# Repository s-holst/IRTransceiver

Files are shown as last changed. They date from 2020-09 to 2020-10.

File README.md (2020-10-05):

# IRTransceiver

A [Pmod](https://reference.digilentinc.com/reference/pmod/start) for emitting and receiving baseband IR signals.
It can be used to decode and emulate IR remote controls, IR communication or other IR-based sensors.

<p align="center">
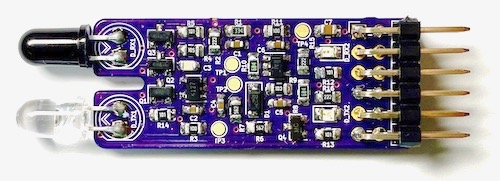
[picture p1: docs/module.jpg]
IR Transceiver Pmod Image
  
</p>

This module contains simple analog signal conditioning circuitry to connect a LED and a photodiode to FPGAs or microcontrollers.
The interface is a 12-pin Pmod (Spec B) with the following pinout:
* P1: TX, input, active high, controls the IR LED via a simple MOSFET.
* P2: GND
* P3: RX, output, is pulled high if the photodiode receives a stronger-than-average IR light.
* P4: GND
* P5, P11: GND (Pmod power supply pins)
* P6, P12: 3.3V (Pmod power supply pins)
* P7-P10: Not connected

The receiver contains a transimpedance amplifier, a high-pass filter and comparator to produce a clean digital signal.
The high-pass rejects ambient light along with signals slower than about 10 kHz, the usable bandwidth is about 100 kHz.
The receiver circuit was inspired by [IRis](https://github.com/devttys0/IRis).

## PYNQ Example Notebook

If you have a PYNQ-enabled FPGA-board, load [PYNQ_IR_Communication.ipynb](PYNQ_IR_Communication.ipynb) onto it to explore an example of sending and receiving IR signals.
This notebook works with the BaseOverlay and is completely self-contained not needing any additional drivers.
It expects an IRTransceiver connected to PMODA.

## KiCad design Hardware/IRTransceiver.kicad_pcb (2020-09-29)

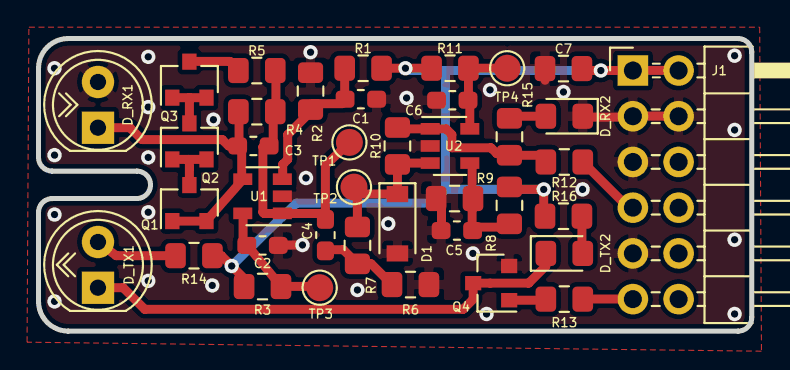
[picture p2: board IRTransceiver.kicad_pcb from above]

Board: 2 copper layers, 39.6 x 16.3 mm, 40 parts (1 on the bottom side), 21 nets.

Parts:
C1, C2, C4, C5, C6: 100n; C_0603_1608Metric_Pad1.05x0.95mm_HandSolder
C3: 2p2; C_0603_1608Metric_Pad1.05x0.95mm_HandSolder
C7: 10u; C_0805_2012Metric_Pad1.15x1.40mm_HandSolder
D1: MBR0520; D_SOD-123
D_RX1: SFH213FA; LED_D5.0mm_IRBlack
D_RX2: LED YELLOW; LED_0805_2012Metric_Pad1.15x1.40mm_HandSolder
D_TX1: SFH4550; LED_D5.0mm_IRGrey
D_TX2: LED BL; LED_0805_2012Metric_Pad1.15x1.40mm_HandSolder
J1: Conn_02x06_Top_Bottom; PinHeader_2x06_P2.54mm_Horizontal
LOGO1: Logo_Open_Hardware_Small; OSHW-Logo_7.5x8mm_SilkScreen
Q1, Q2, Q3: MMBF4117; SOT-23
Q4: ZVN3306F; SOT-23
R1: 330k; R_0805_2012Metric_Pad1.15x1.40mm_HandSolder
R2: 22k; R_0805_2012Metric_Pad1.15x1.40mm_HandSolder
R3, R11: 10; R_0805_2012Metric_Pad1.15x1.40mm_HandSolder
R4: 1M; R_0805_2012Metric_Pad1.15x1.40mm_HandSolder
R5, R12, R13: 100; R_0805_2012Metric_Pad1.15x1.40mm_HandSolder
R6, R7: 5k6; R_0805_2012Metric_Pad1.15x1.40mm_HandSolder
R8, R10: 680k; R_0805_2012Metric_Pad1.15x1.40mm_HandSolder
R9: 10k; R_0805_2012Metric_Pad1.15x1.40mm_HandSolder
R14: 37; R_0805_2012Metric_Pad1.15x1.40mm_HandSolder
R15, R16: 2k2; R_0805_2012Metric_Pad1.15x1.40mm_HandSolder
TP1, TP2, TP3, TP4: TestPoint; TestPoint_Pad_D1.5mm
U1: TSV911ILT; SOT-23-5
U2: TLV3201; SOT-23-5

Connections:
+3V3: C7.2, J1.1, J1.2, R1.2, R3.2, R8.2, R11.2, R14.2, R16.2
/RX: J1.7, R12.2
/TX: J1.11, R13.1
GND: C1.1, C2.1, C5.2, C6.1, C7.1, D1.2, D_RX1.2, D_RX2.1, J1.3, J1.4, J1.5, J1.9, Q4.2, R2.1, R6.1, R9.1, U1.2, U2.2
unnamed: C1.2, R1.1, R2.2, U1.3
unnamed: C2.2, R3.1, TP3.1, U1.5
unnamed: C3.1, C4.2, R4.1, R5.1, TP1.1, U1.1
unnamed: C3.2, D_RX1.1, Q1.1, Q1.2, R4.2, U1.4
unnamed: C4.1, R6.2, R7.2
unnamed: C5.1, R8.1, R9.2, U2.4
unnamed: C6.2, R11.1, TP4.1, U2.5
unnamed: D1.1, R7.1, R10.1, TP2.1, U2.3
unnamed: D_RX2.2, R15.1
unnamed: D_TX1.1, D_TX2.1, Q4.3
unnamed: D_TX1.2, R14.1
unnamed: D_TX2.2, R16.1
unnamed: Q1.3, Q2.1, Q2.2
unnamed: Q2.3, Q3.1, Q3.2
unnamed: Q3.3, R5.2
unnamed: Q4.1, R13.2
unnamed: R10.2, R12.1, R15.2, U2.1

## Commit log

2020-02-06 Rev1 Design
    [IRTransceiver.kicad_pcb, IRTransceiver.sch]
2020-09-29 KiCad settings update (no design change)
    [IRTransceiver.kicad_pcb]
2020-09-29 move HW to subfolder
    [IRTransceiver.kicad_pcb, IRTransceiver.sch]

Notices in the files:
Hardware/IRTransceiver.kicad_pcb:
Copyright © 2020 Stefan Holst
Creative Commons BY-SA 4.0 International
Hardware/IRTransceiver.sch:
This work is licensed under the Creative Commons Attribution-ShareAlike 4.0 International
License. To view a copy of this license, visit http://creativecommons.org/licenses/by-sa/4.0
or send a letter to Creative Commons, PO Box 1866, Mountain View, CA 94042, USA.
